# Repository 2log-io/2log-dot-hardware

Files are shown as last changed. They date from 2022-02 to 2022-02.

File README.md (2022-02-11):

# 2log-dot-hardware

This repository contains the KiCad Project for the 2log Dot. The hardware is designed to be used with [2log Dot](https://github.com/2log-io/2log-dot "2log Dot Firmware")

## Parts

The PCB consists of a 4-Layer stack. All required parts are through hole components with the exception of the capacitor C1 which is a combined footprint.
Besides the PCB itself you need the following parts:
  * 24 Led WS2812B Ring with 4 contacts (diameter 66mm)
  * SMD Capacitor 5mm diameter, about 10uF
  * (alternative) THT Capacitor, about 10uF
  * Wemos D1 mini ESP32 (ESP8266 will not work)
  * PN532 RFID Reader V3 (red modules, sold under elechouse brand or clones)
  * mini pushbutton (the tiny black/silver ones)
  * _(optional) 14 Pin Male and 13 Pin Female 2.54mm Pin Header/Socket for expansion port_
  
## Images

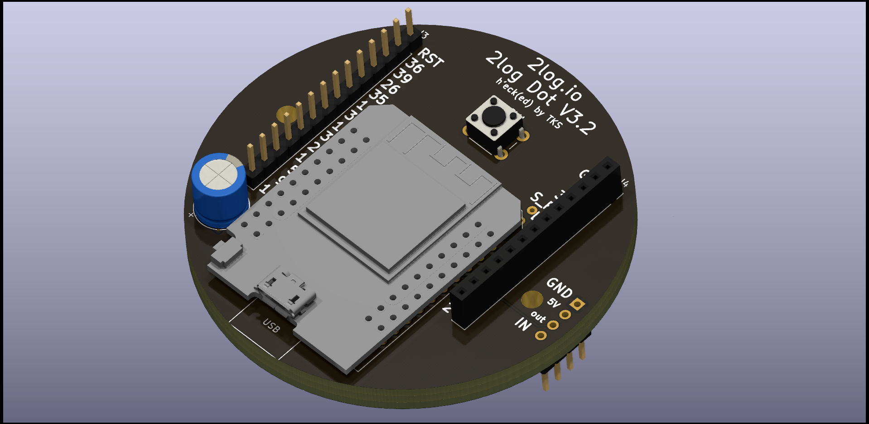
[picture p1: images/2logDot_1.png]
esp side

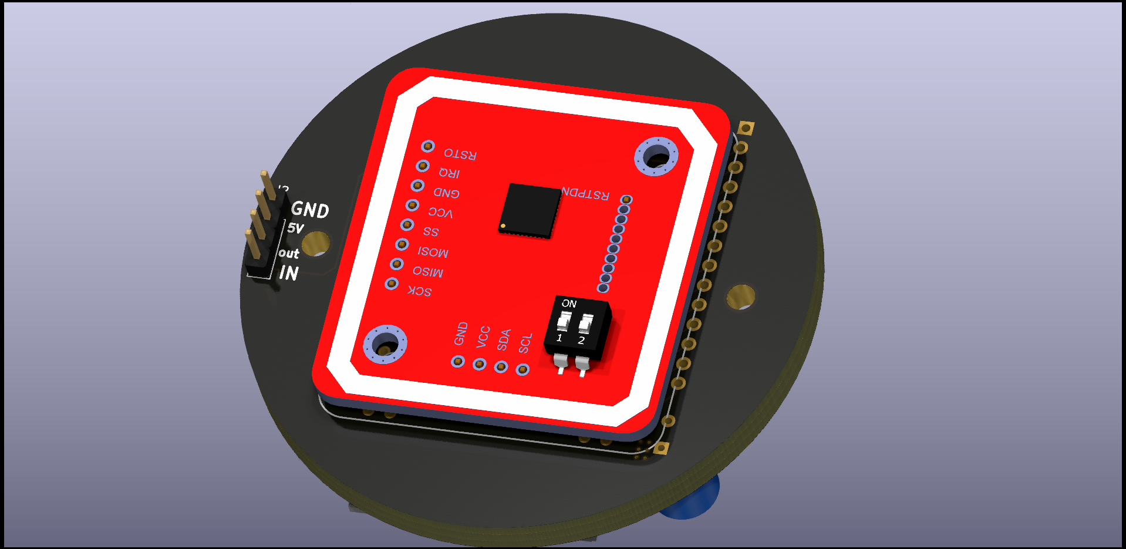
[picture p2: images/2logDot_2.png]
rfid side


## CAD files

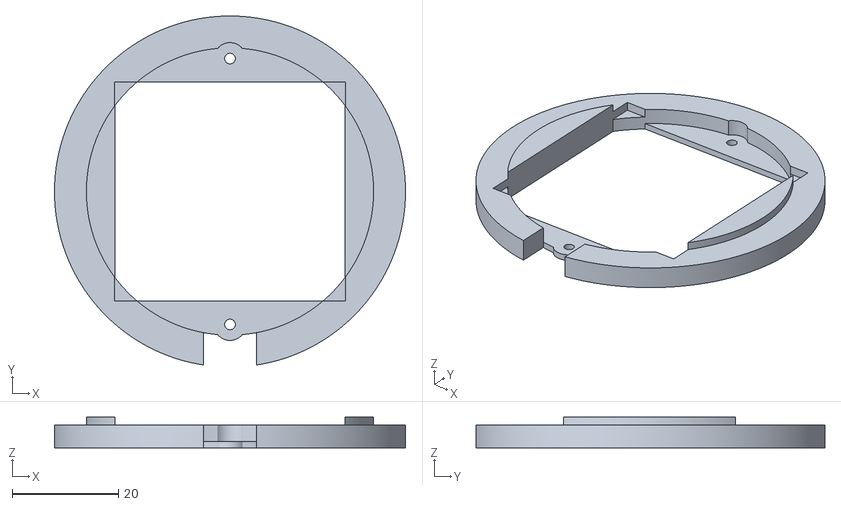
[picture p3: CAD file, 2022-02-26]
reader_led_attachment.stl
66.0 x 65.6 x 5.80

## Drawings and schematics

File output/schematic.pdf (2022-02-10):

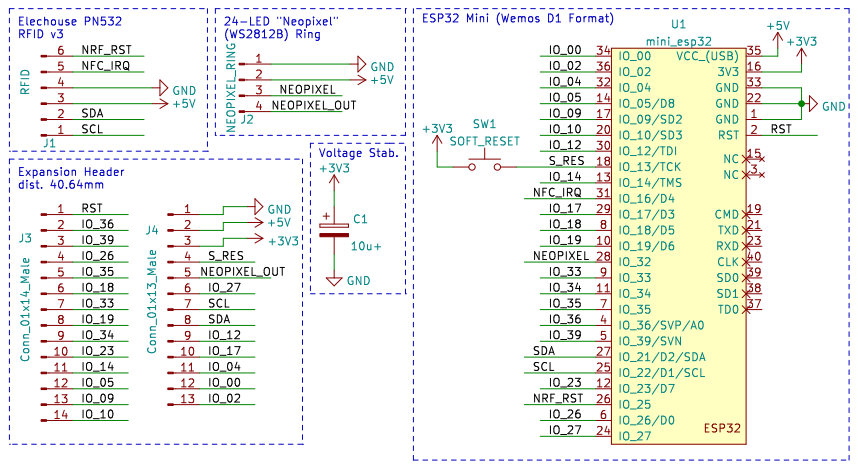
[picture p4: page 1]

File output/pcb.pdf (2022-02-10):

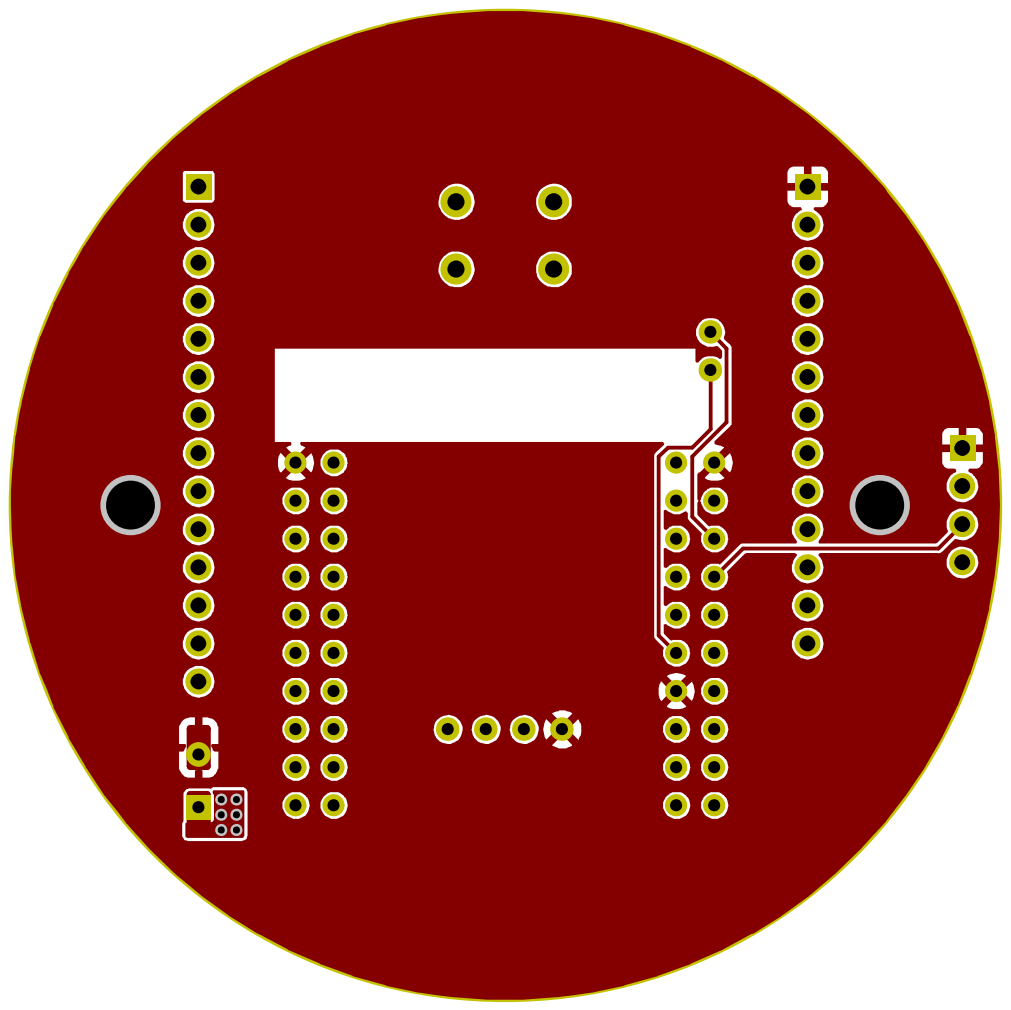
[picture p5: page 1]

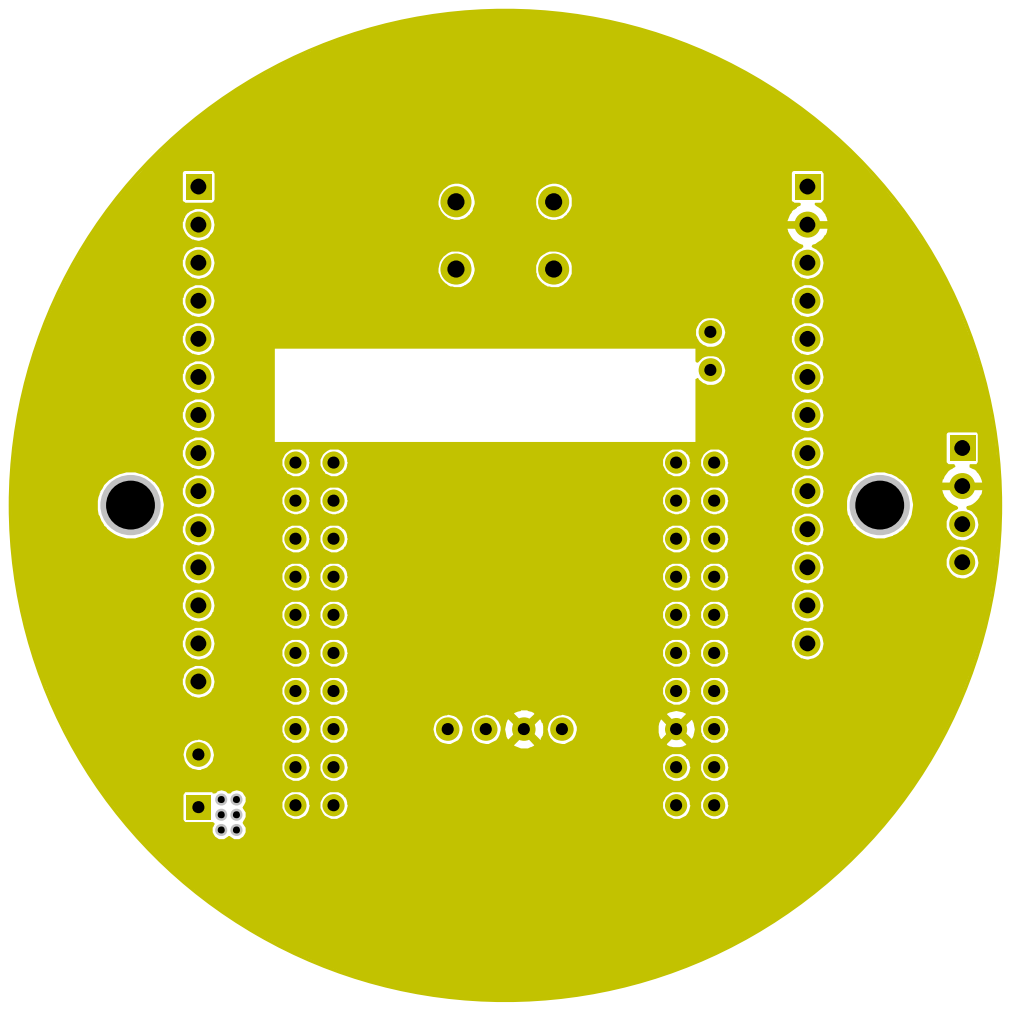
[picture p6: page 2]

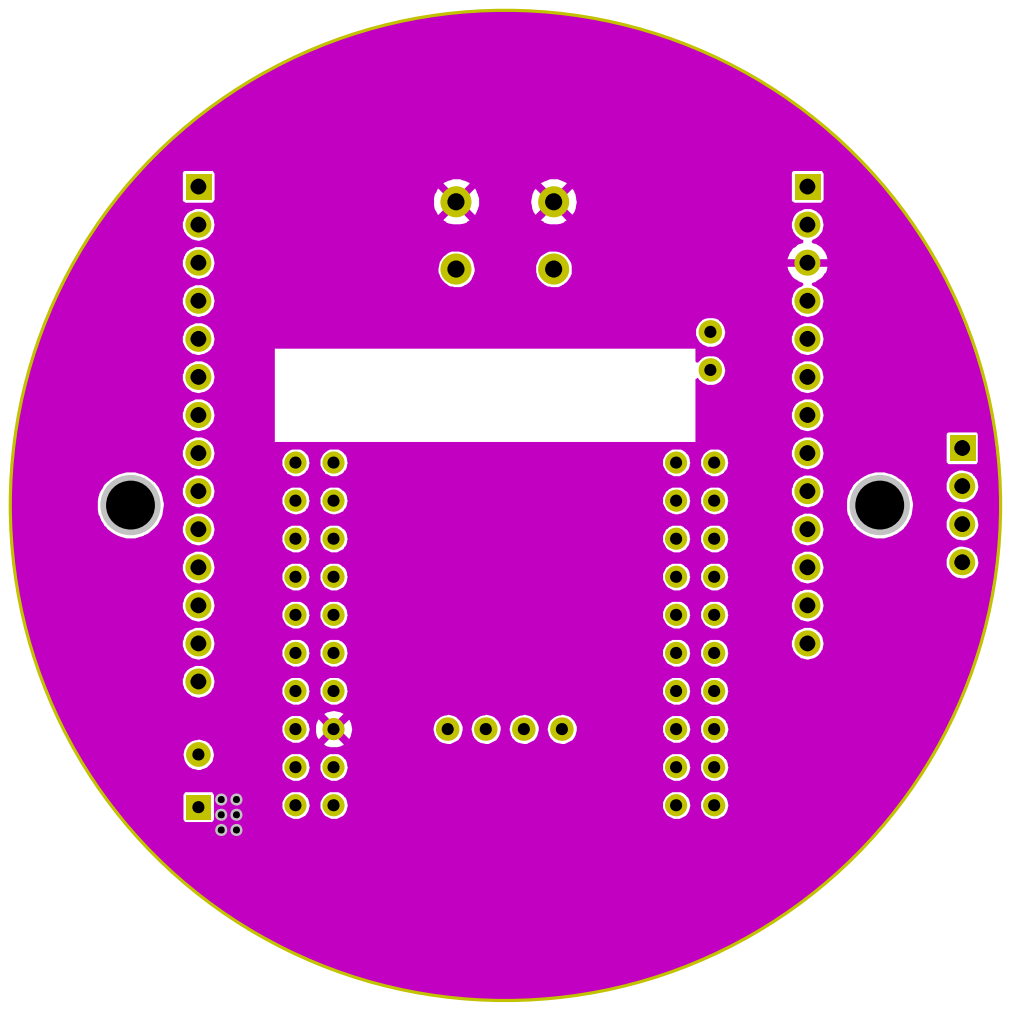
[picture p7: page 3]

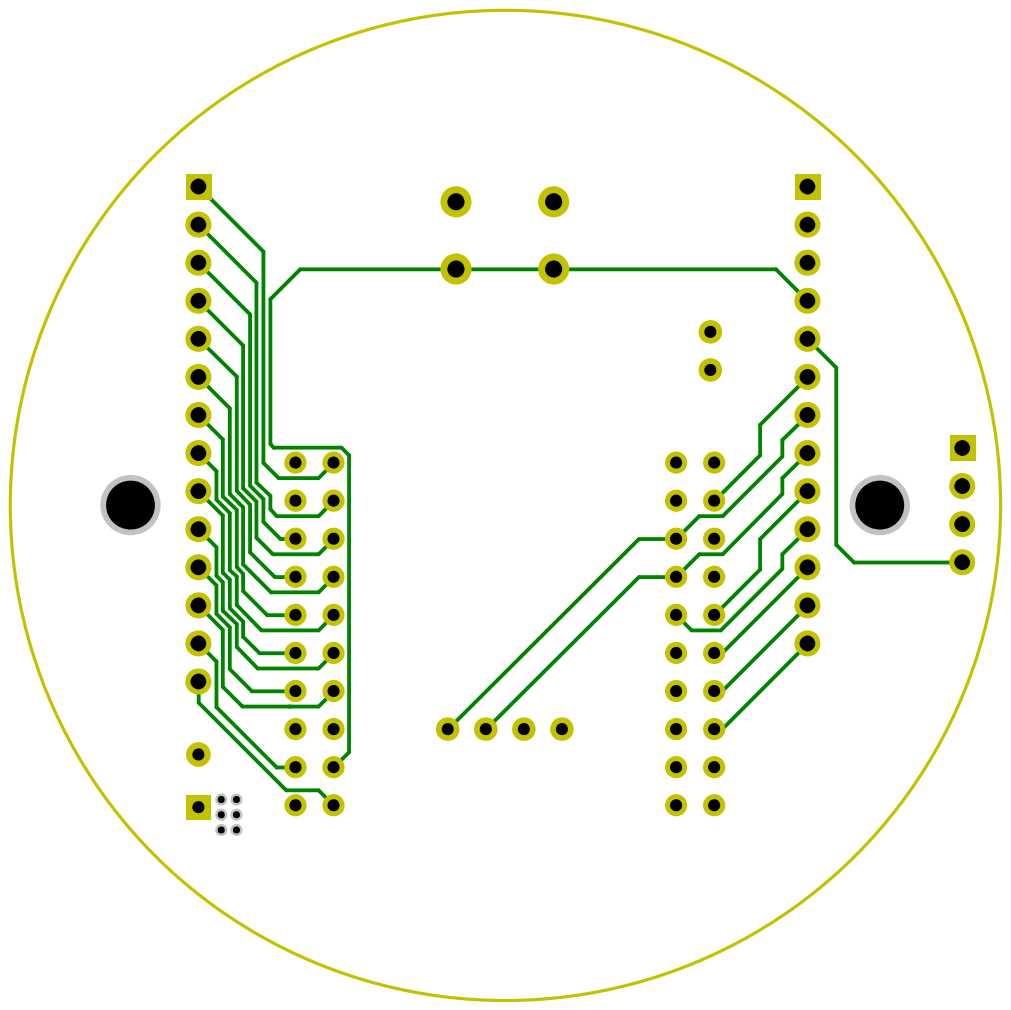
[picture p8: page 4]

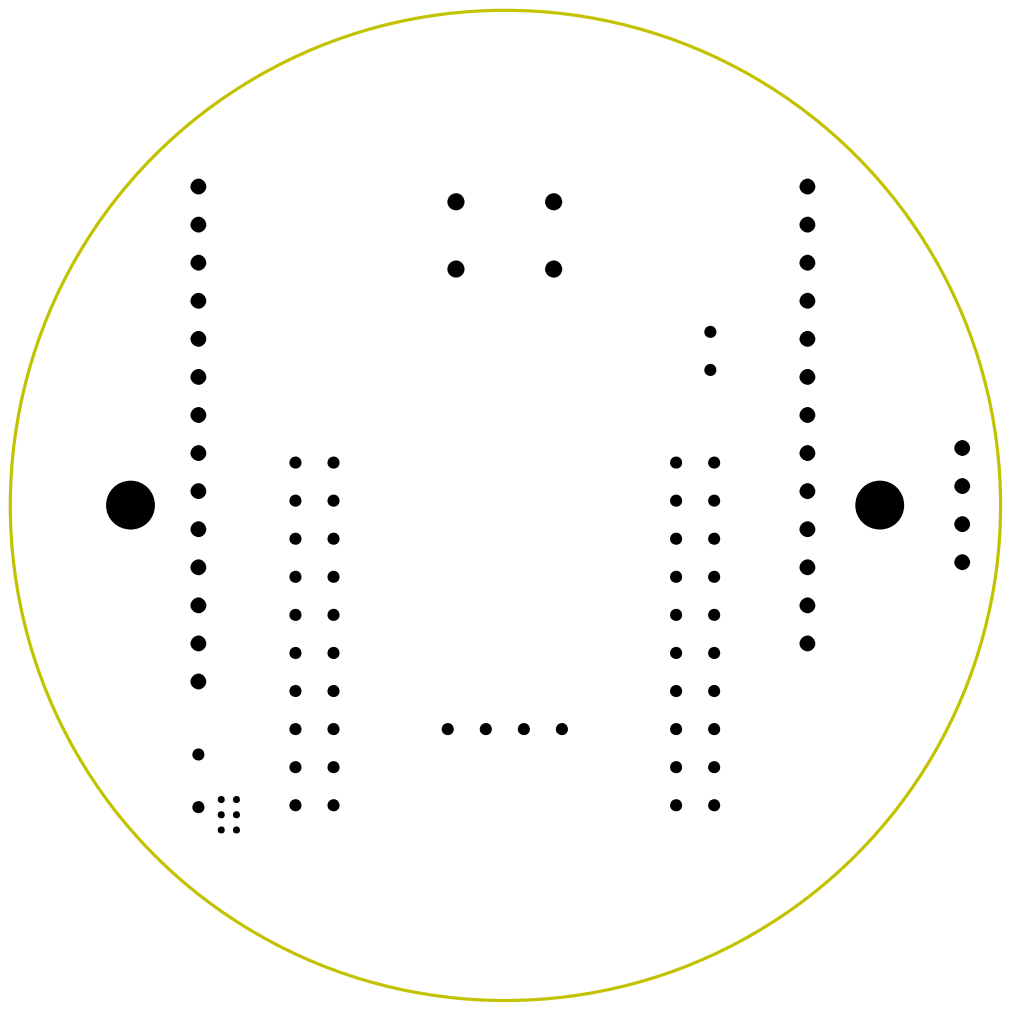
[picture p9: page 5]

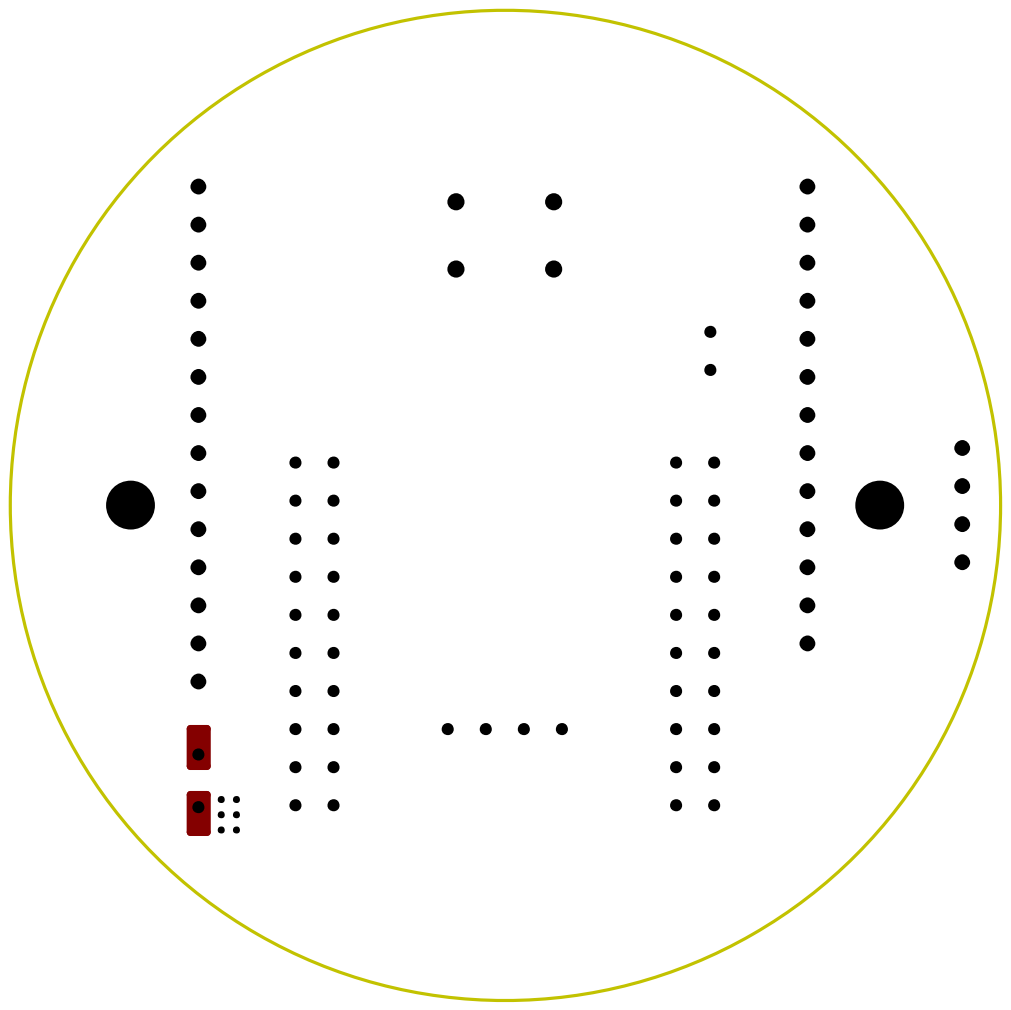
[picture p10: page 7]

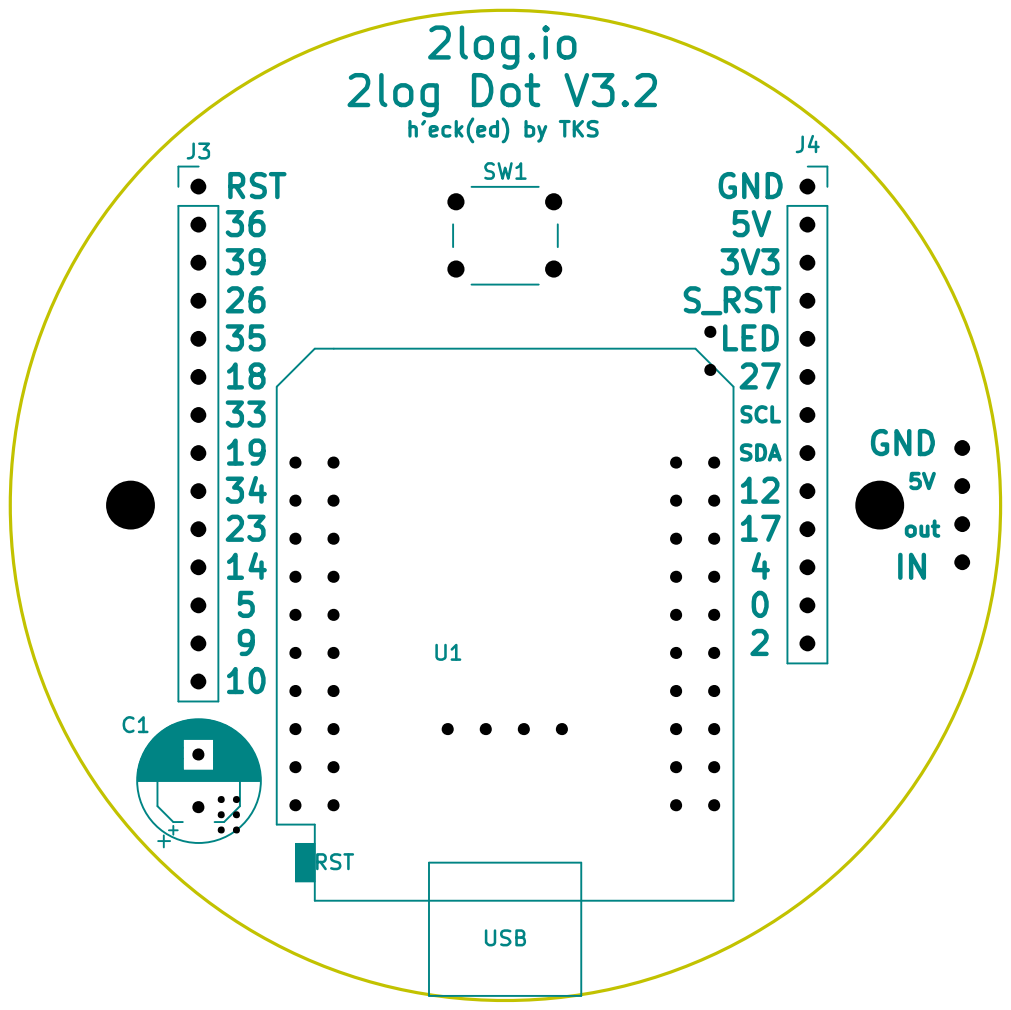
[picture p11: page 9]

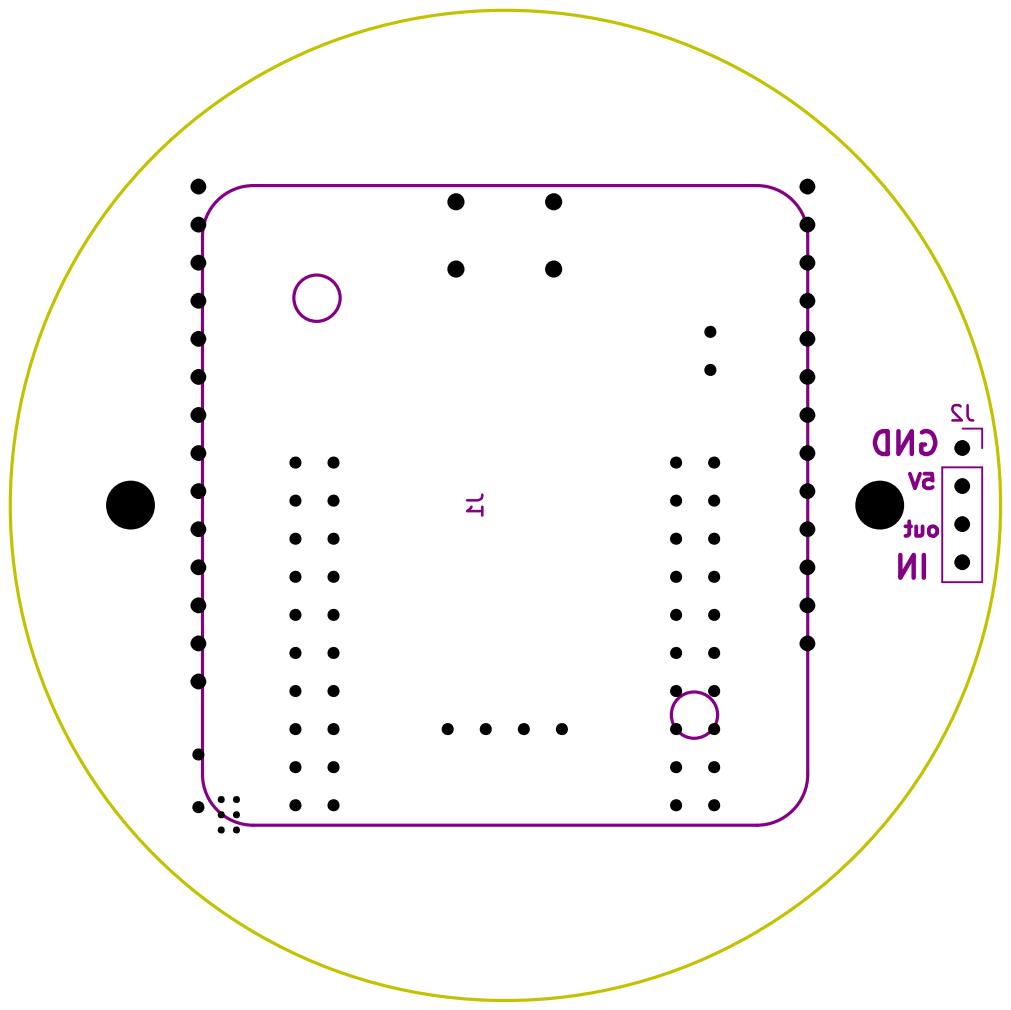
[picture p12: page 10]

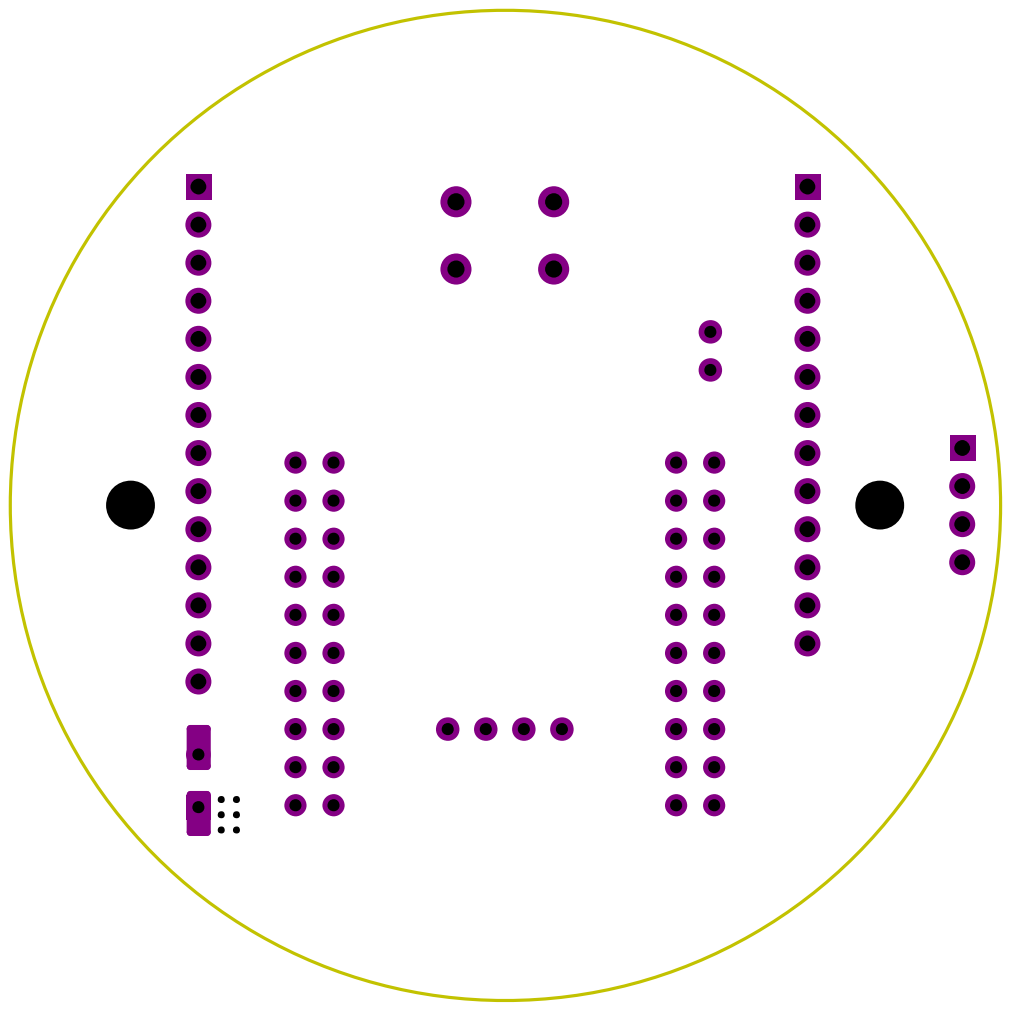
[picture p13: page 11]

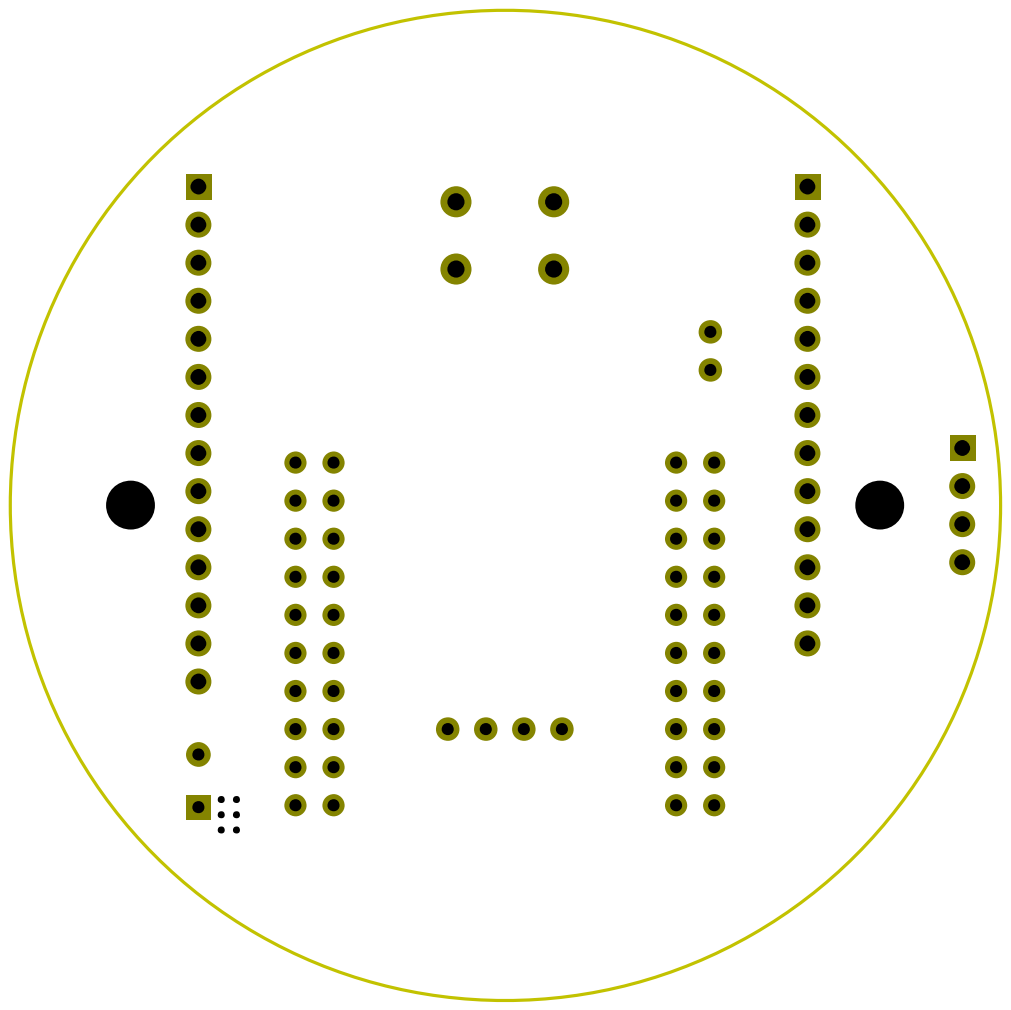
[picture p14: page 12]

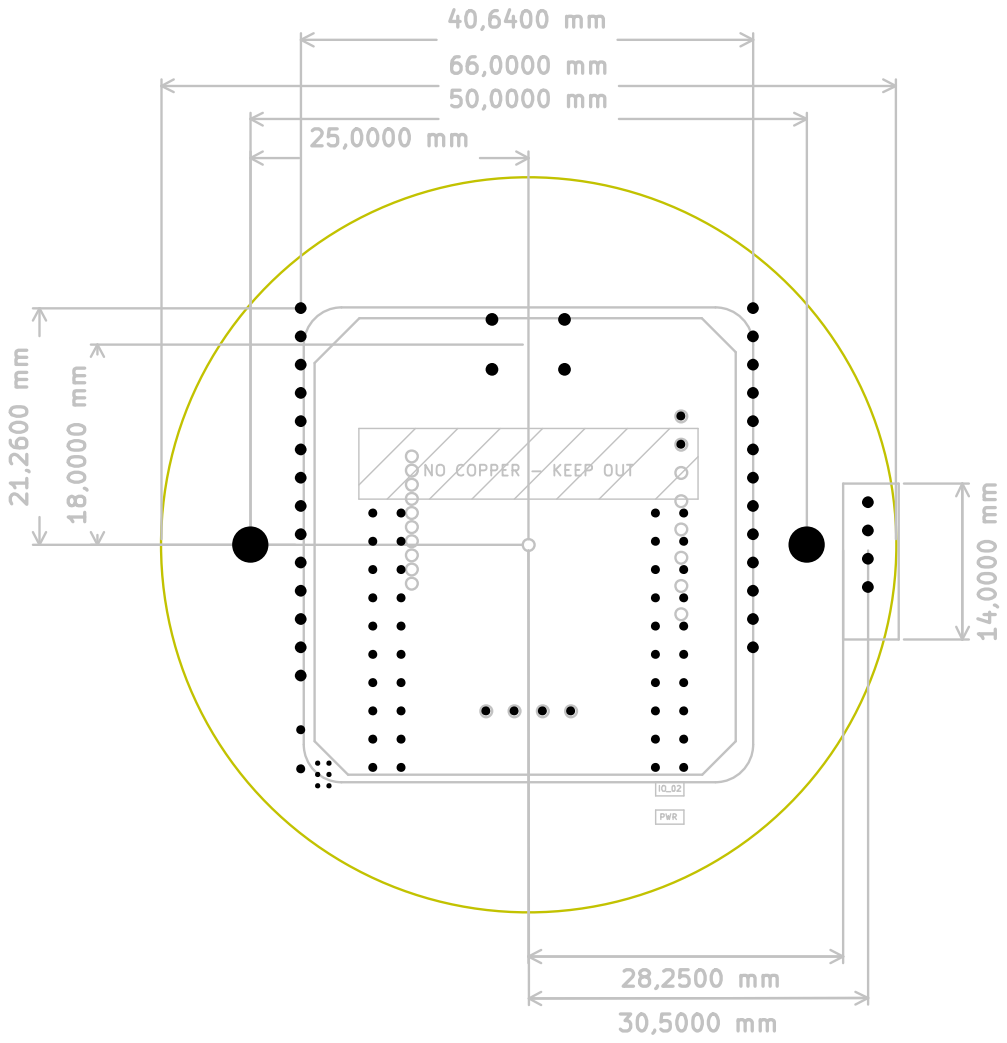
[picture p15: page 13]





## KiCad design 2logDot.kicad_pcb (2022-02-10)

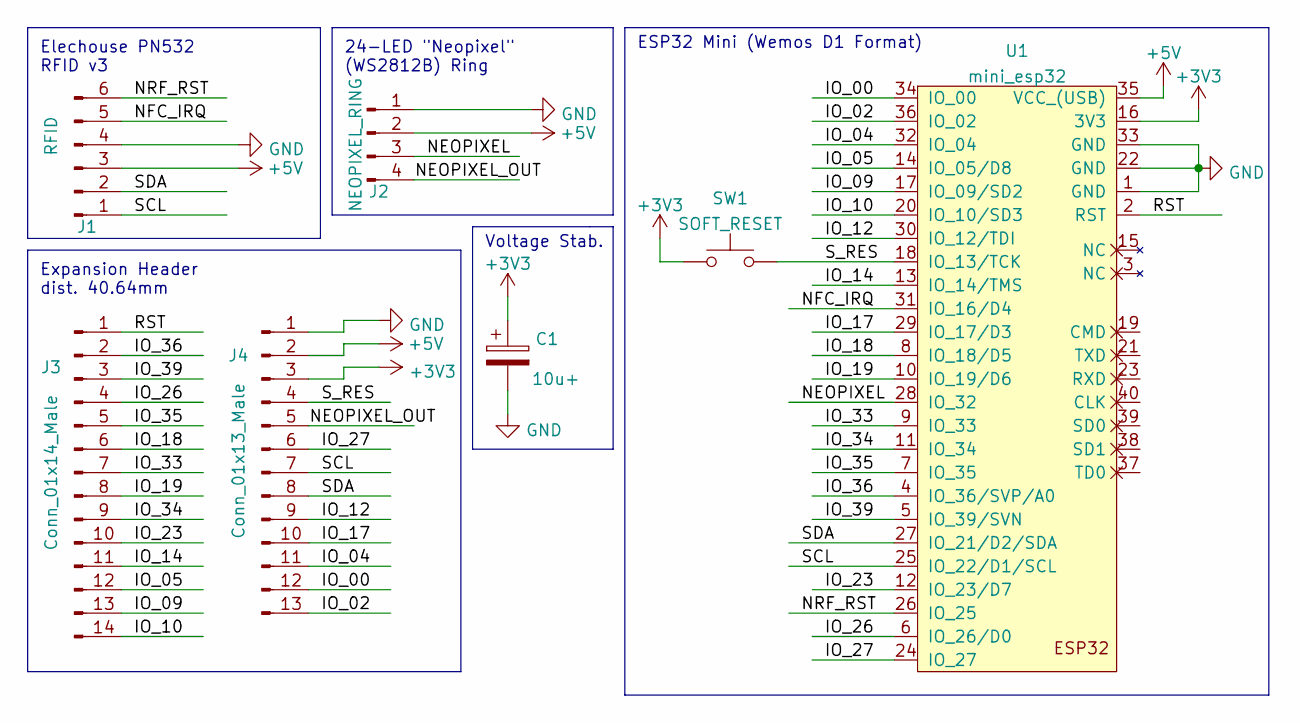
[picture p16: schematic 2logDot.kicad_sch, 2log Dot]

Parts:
C1: 10u+; CP_Elec_5x3
J1: RFID; 2log_elechouse_pn532
J2: NEOPIXEL_RING; PinHeader_1x04_P2.54mm_Vertical
J3: Conn_01x14_Male; PinHeader_1x14_P2.54mm_Vertical
J4: Conn_01x13_Male; PinSocket_1x13_P2.54mm_Vertical
SW1: SOFT_RESET; SW_PUSH_6mm
U1: mini_esp32; ESP32_mini

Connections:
+3V3: C1.1, J4.3, SW1.1, U1.16 (3V3)
+5V: J1.3, J2.2, J4.2, U1.35 (VCC_(USB))
/IO_00: J4.12, U1.34 (IO_00)
/IO_02: J4.13, U1.36 (IO_02)
/IO_04: J4.11, U1.32 (IO_04)
/IO_05: J3.12, U1.14 (IO_05/D8)
/IO_09: J3.13, U1.17 (IO_09/SD2)
/IO_10: J3.14, U1.20 (IO_10/SD3)
/IO_12: J4.9, U1.30 (IO_12/TDI)
/IO_14: J3.11, U1.13 (IO_14/TMS)
/IO_17: J4.10, U1.29 (IO_17/D3)
/IO_18: J3.6, U1.8 (IO_18/D5)
/IO_19: J3.8, U1.10 (IO_19/D6)
/IO_23: J3.10, U1.12 (IO_23/D7)
/IO_26: J3.4, U1.6 (IO_26/D0)
/IO_27: J4.6, U1.24 (IO_27)
/IO_33: J3.7, U1.9 (IO_33)
/IO_34: J3.9, U1.11 (IO_34)
/IO_35: J3.5, U1.7 (IO_35)
/IO_36: J3.2, U1.4 (IO_36/SVP/A0)
/IO_39: J3.3, U1.5 (IO_39/SVN)
/NEOPIXEL: J2.3, U1.28 (IO_32)
/NEOPIXEL_OUT: J2.4, J4.5
/NFC_IRQ: J1.5, U1.31 (IO_16/D4)
/NRF_RST: J1.6, U1.26 (IO_25)
/RST: J3.1, U1.2 (RST)
/SCL: J1.1, J4.7, U1.25 (IO_22/D1/SCL)
/SDA: J1.2, J4.8, U1.27 (IO_21/D2/SDA)
/S_RES: J4.4, SW1.2, U1.18 (IO_13/TCK)
GND: C1.2, J1.4, J2.1, J4.1, U1.1 (GND), U1.22 (GND), U1.33 (GND)

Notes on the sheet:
ESP32 Mini (Wemos D1 Format)
24-LED "Neopixel" (WS2812B) Ring
Voltage Stab.
Elechouse PN532 RFID v3
Expansion Header dist. 40.64mm

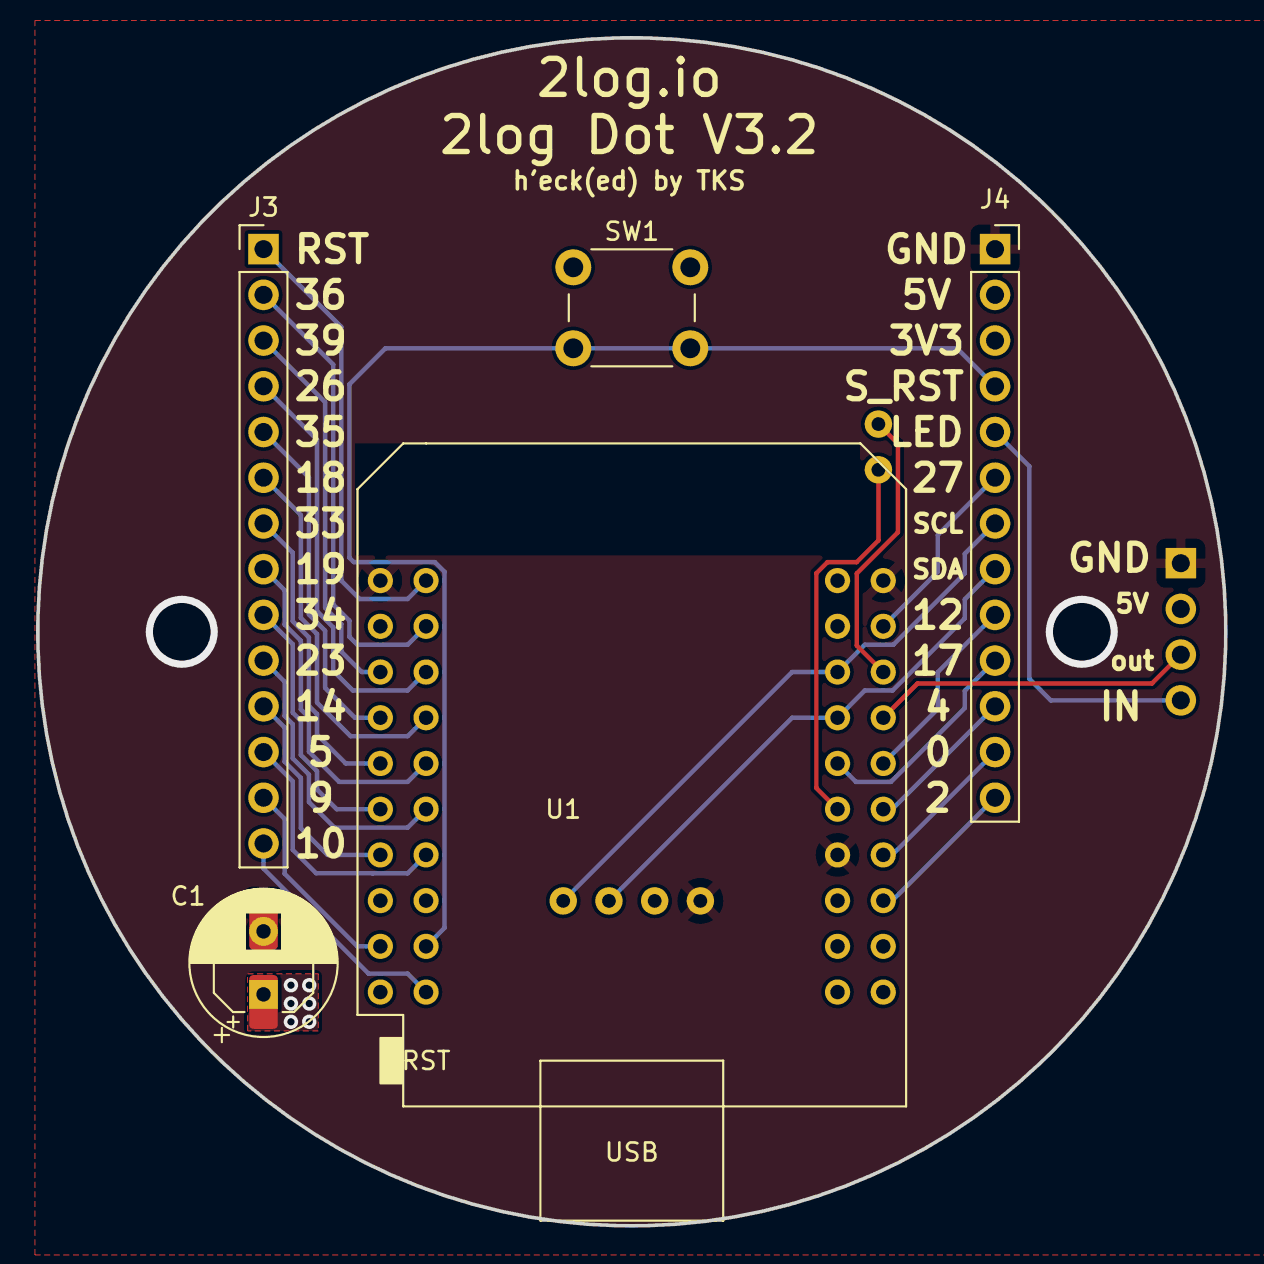
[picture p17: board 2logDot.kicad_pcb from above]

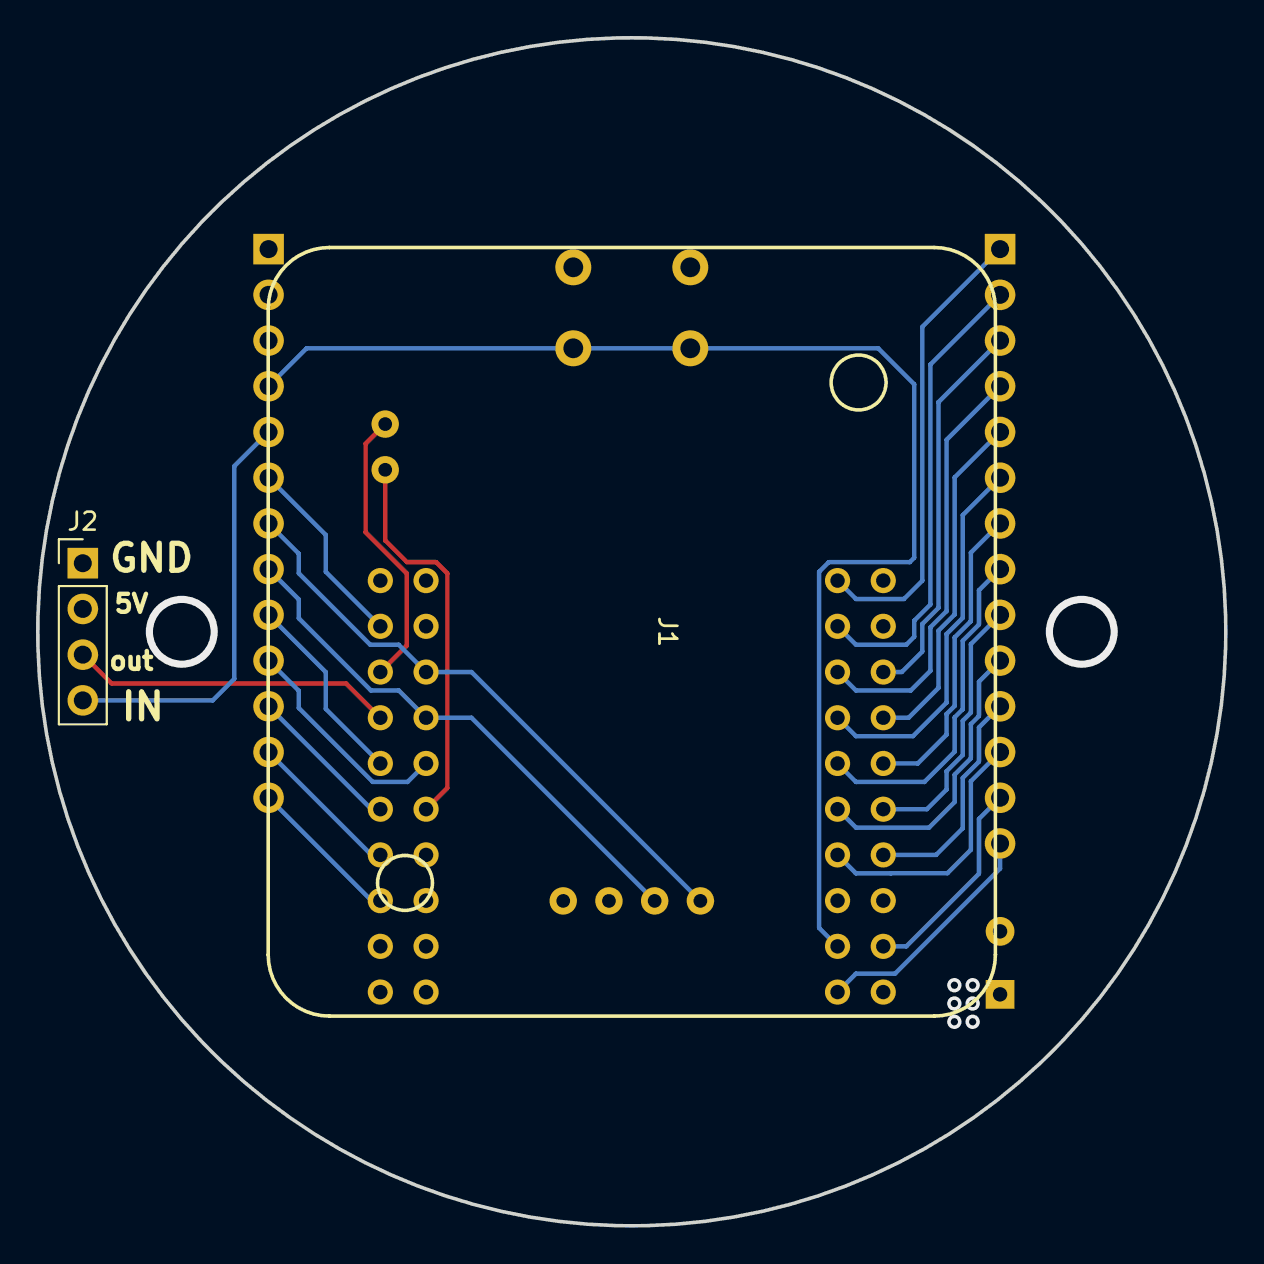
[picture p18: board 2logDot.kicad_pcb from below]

Board: 4 copper layers, 66.0 x 66.0 mm, 7 parts (2 on the bottom side), 30 nets.

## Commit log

2022-02-10 Added V3.2
    [2logDot.kicad_pcb, 2logDot.kicad_sch]
2022-02-26 Add .stl files
    [reader_led_attachment.stl]
